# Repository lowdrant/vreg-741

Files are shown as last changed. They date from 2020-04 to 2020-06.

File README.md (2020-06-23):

# vreg-741
Variable linear voltage regulator based on the classic 741 op amp

## License
If you use this PCB, specifically the files used with PCBNew, in a design or as the basis for a design, excepting as an educational reference or example, I request that you leave my name on the circuit board and credit me accordingly for the design. Excepting any attempt to copyright this design, I place no further requirements or restrictions on its use, replication, fabrication, or any other purpose. 

The schematic itself is of a basic voltage regulation circuit, which I believe cannot be rightfully claimed as intellectual property.

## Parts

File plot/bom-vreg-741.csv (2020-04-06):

Id | Designator | Package | Quantity | Designation | Supplier and ref
1 | SW1 | SW_DIP_SPSTx01_Slide_Omron_A6S-110x_W8.9mm_P2.54mm | 1 | A6SN-1104
2 | J2,J1 | TerminalBlock_Phoenix_MKDS-1,5-2-5.08_1x02_P5.08mm_Horizontal | 2 | 1729128
3 | D1,D2 | LED_0603_1608Metric_Pad1.05x0.95mm_HandSolder | 2 | LO Q976-PS-25-0-20-R18
4 | U1 | SOIC-8_3.9x4.9mm_P1.27mm | 1 | UA741CDR
5 | Q2 | SOT-223-3_TabPin2 | 1 | 2STN1550
6 | D3 | D_SOT-23_ANK | 1 | MMBZ5223BLT1G
7 | C1,C2 | C_0603_1608Metric_Pad1.05x0.95mm_HandSolder | 2 | C0603C101J1GACTU
8 | C3 | C_0603_1608Metric_Pad1.05x0.95mm_HandSolder | 1 | 600S0R1BT250XT
9 | R1,R2,R4 | R_0603_1608Metric_Pad1.05x0.95mm_HandSolder | 3 | RC0603JR-0710KL
10 | R3 | R_0603_1608Metric_Pad1.05x0.95mm_HandSolder | 1 | RC0603JR-071KL
11 | Q1 | SOT-223-3_TabPin2 | 1 | FQT5P10TF
12 | RV1 | Potentiometer_Bourns_3214W_Vertical | 1 | 3214W-1-105E

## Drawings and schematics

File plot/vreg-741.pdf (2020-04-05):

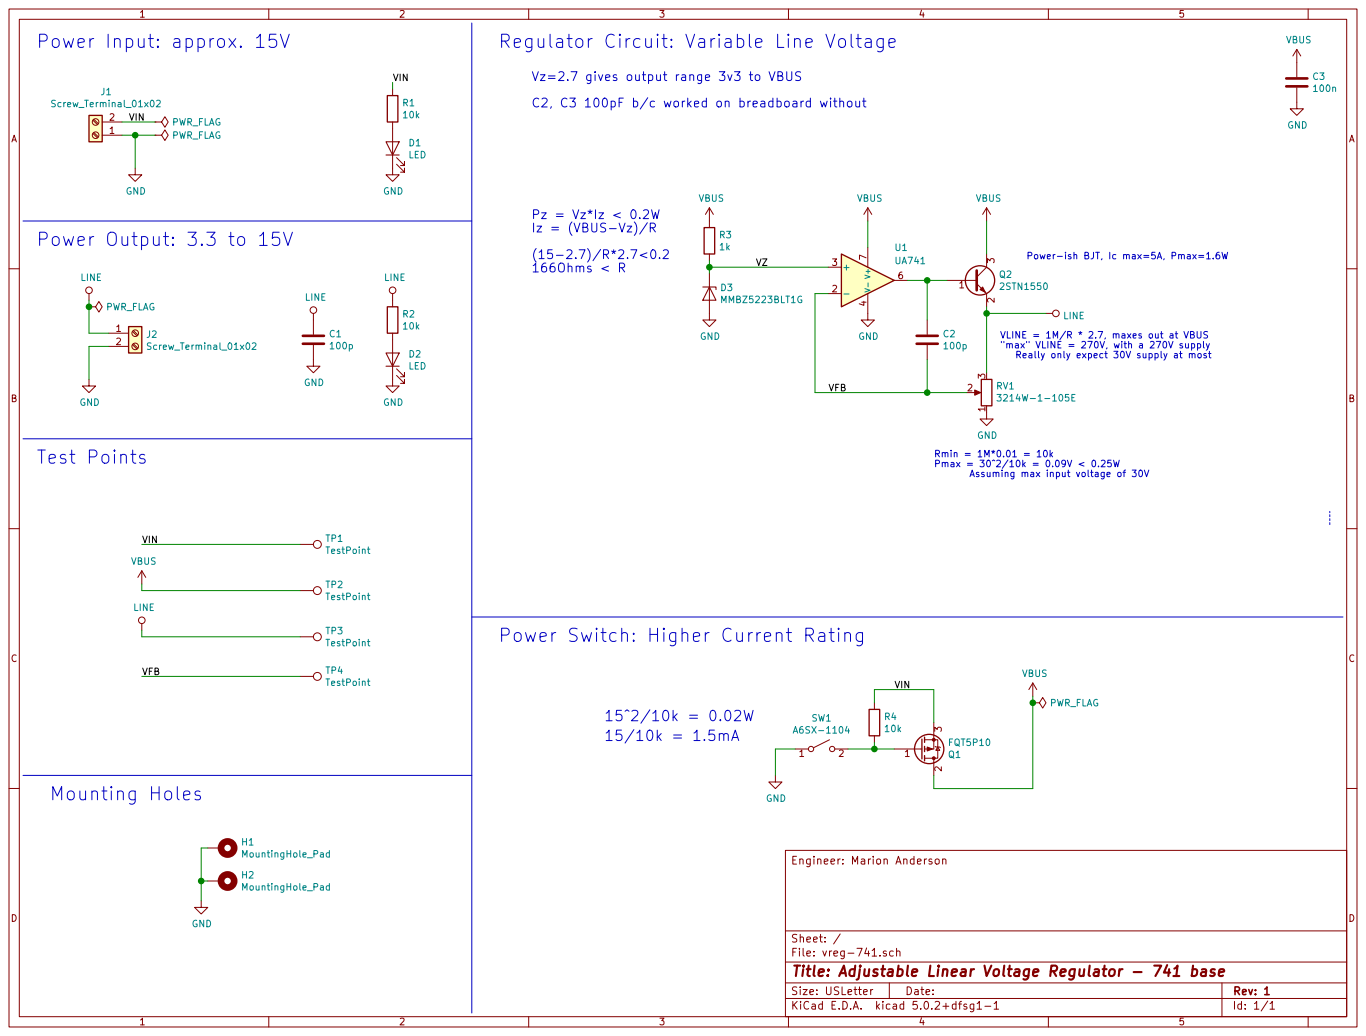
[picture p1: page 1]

100n VBUS GND Power Input: approx. 15V

Regulator Circuit: Variable Line Voltage

Vz=2.7 gives output range 3v3 to VBUS

Really only expect 30V supply at most Power-ish BJT, Ic max=5A, Pmax=1.6W

VLINE = 1M/R * 2.7, maxes out at VBUS
"max" VLINE = 270V, with a 270V supply

TP2 TestPoint TP3 TestPoint TP4 TestPoint Test Points

Rmin = 1M*0.01 = 10k Pmax = 30^2/10k = 0.09V < 0.25W
Assuming max input voltage of 30V

VIN Power Switch: Higher Current Rating

File: vreg-741.sch Sheet: / Engineer: Marion Anderson

Id: 1/1 Title: Adjustable Linear Voltage Regulator - 741 base

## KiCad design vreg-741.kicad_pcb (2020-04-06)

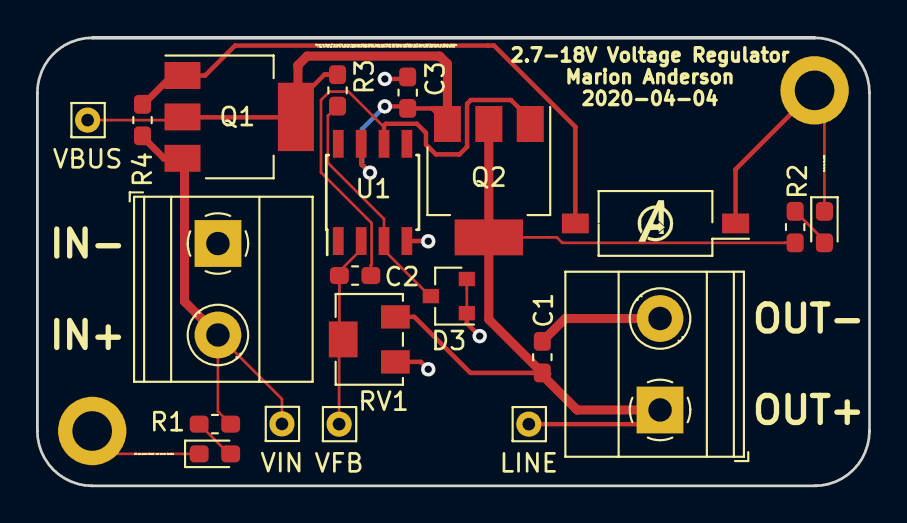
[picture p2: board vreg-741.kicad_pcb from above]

Board: 2 copper layers, 46.2 x 24.9 mm, 23 parts (0 on the bottom side), 10 nets.

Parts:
C1, C2: 100p; C_0603_1608Metric_Pad1.05x0.95mm_HandSolder
C3: 100n; C_0603_1608Metric_Pad1.05x0.95mm_HandSolder
D1, D2: 475-2486-1-ND; LED_0603_1608Metric_Pad1.05x0.95mm_HandSolder
D3: MMBZ5223BLT1G; D_SOT-23_ANK
H2, H3: MountingHole_Pad; MountingHole_2.2mm_M2_DIN965_Pad
J1, J2: 1729128; TerminalBlock_Phoenix_MKDS-1,5-2-5.08_1x02_P5.08mm_Horizont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
LINE: TestPoint; Pin_D0.7mm_L6.5mm_W1.8mm_FlatFork
Q1: FQT5P10; SOT-223-3_TabPin2
Q2: 2STN1550; SOT-223-3_TabPin2
R1, R2, R4: 10k; R_0603_1608Metric_Pad1.05x0.95mm_HandSolder
R3: 1k; R_0603_1608Metric_Pad1.05x0.95mm_HandSolder
RV1: 3214W-1-105E; Potentiometer_Bourns_3214W_Vertical
SW1: A6SN-1104; SW_DIP_SPSTx01_Slide_Omron_A6S-110x_W8.9mm_P2.54mm
U1: UA741CDR‎; SOIC-8_3.9x4.9mm_P1.27mm
VBUS: TestPoint; Pin_D0.7mm_L6.5mm_W1.8mm_FlatFork
VFB: TestPoint; Pin_D0.7mm_L6.5mm_W1.8mm_FlatFork
VIN: TestPoint; Pin_D0.7mm_L6.5mm_W1.8mm_FlatFork

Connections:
/VFB: C2.2, RV1.2, U1.2, VFB.1
/VIN: J1.2, Q1.3, R1.1, R4.1, VIN.1
/VZ: D3.1, R3.2, U1.3
GND: C1.2, C3.2, D1.1, D2.1, D3.2, H2.1, H3.1, J1.1, J2.2, RV1.1, SW1.1, U1.4
LINE: C1.1, J2.1, LINE.1, Q2.2, R2.1, RV1.3
unnamed: C2.1, Q2.1, U1.6
unnamed: D1.2, R1.2
unnamed: D2.2, R2.2
unnamed: Q1.1, R4.2, SW1.2
VBUS: C3.1, Q1.2, Q2.3, R3.1, U1.7, VBUS.1

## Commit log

2020-04-05 updated part numbers and added manufacturer field
    [vreg-741.sch]
2020-04-06 extra easter eggs
    [bom-vreg-741.csv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]
